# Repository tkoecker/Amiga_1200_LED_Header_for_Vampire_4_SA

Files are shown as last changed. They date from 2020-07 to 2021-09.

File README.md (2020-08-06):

# Amiga 1200 LED Header for Vampire 4 Standalone

I've printed the fantastic Vampire 4 Standalone enclosure by Jörgen Bilander (see https://github.com/jbilander/Vampire_V4_Standalone_Enclosure). It allows to mount an Amiga 1200 LED PCB, however the Vampire 4 SA does not have any header to connect this board. This is why I've made a small adapter PCB that adds an Amiga 1200 LED header to the Vampire 4 SA.

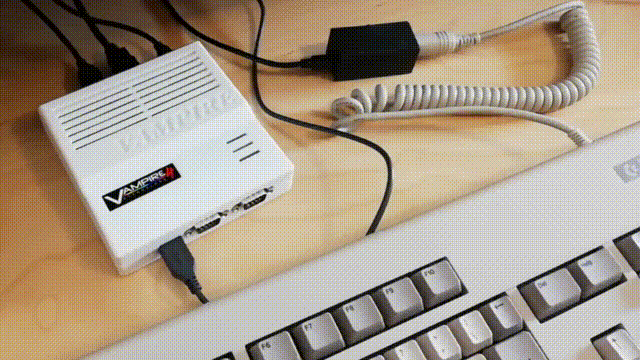
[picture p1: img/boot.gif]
Video of V4SA booting with A1200 LEDs


(LED activity in the image above: Power on, SD card access to load kick rom, Amiga OS booting, Amiga OS mounting/reading SD card)

It uses an IC that provides 4 opamps. One opamp each is used to sense the power and drive LED state, adding only a neglectable additional load to the outputs of the V4SA. The two remaining opamps are for the floppy LED which can be either be triggered from an active low or an active high signal (selectable using a solder jumper).
The chosen opamps have rail-to-rail outputs which allows to drive the LEDs on the Amiga 1200 LED PCB with a similar voltage as the original Amiga 1200 circuitry.

*WARNING:* There is some fine soldering needed to install the PCB on the V4SA. If you do not feel confident doing that, please ask somebody who does. It would be a pitty if you ruin your nice V4SA when installing this board.

Adapter (please note that the images were taken from an old board version, the current one has less solder pads - they are not needed):

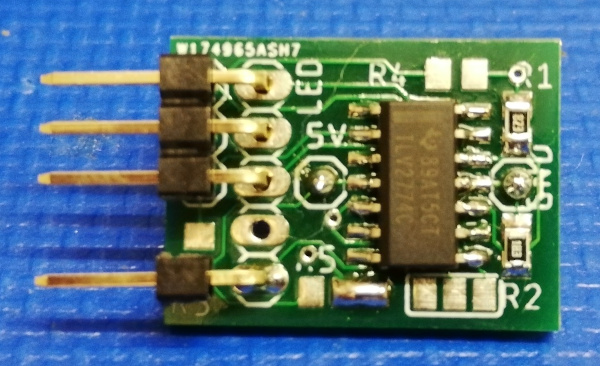
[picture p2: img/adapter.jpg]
Adapter


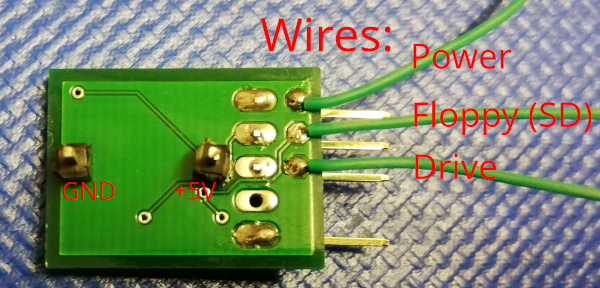
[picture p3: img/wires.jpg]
Adapter wires


The board sits on top of the 68000 pins of the Vampire 4 SA and gets +5V and GND from there.

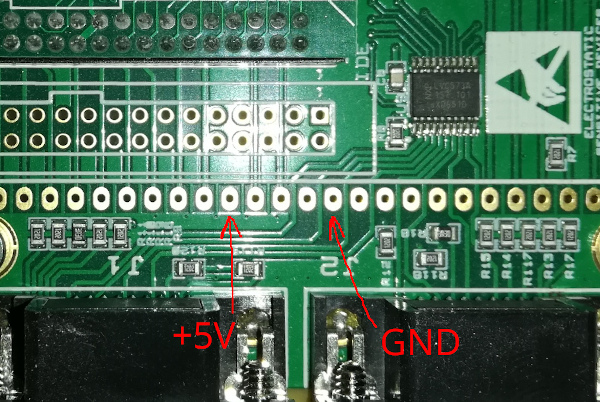
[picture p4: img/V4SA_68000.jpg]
Adapter location


It also needs two wires to the original power and drive LEDs of the V4SA to sense their state.

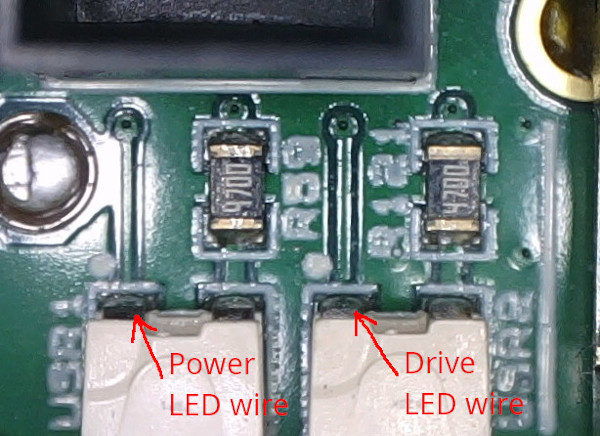
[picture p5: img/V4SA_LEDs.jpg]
Original LED wires


For using the floppy led for the micro-SD card access a wire to pin 2 of the micro-SD card slot of the V4SA is needed.

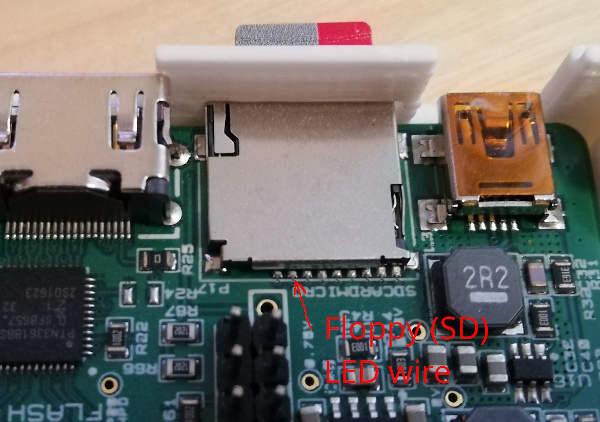
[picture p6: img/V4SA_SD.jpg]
SD wire


If you want use the floppy led you need to connect a solder jumper to select whether the signal is active-low or active-high:

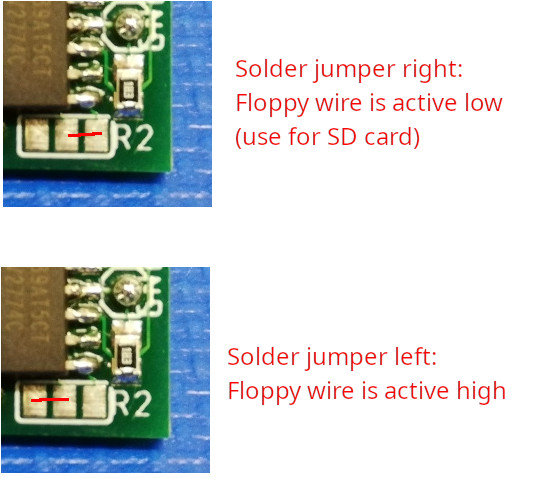
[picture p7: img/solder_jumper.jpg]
Solder jumper


[Link to PCB on PCBWay](https://www.pcbway.com/project/shareproject/Amiga_1200_LED_Header_for_Vampire_4_Standalone.html)

BOM:
- R1, R2: 82 kOhm 0805 SMD resistor
- IC1: TLV2774CD
- 5V/GND pins: 1 pin of a straight pin header each
- LED pin header: 5 pin angled pin header

Images:

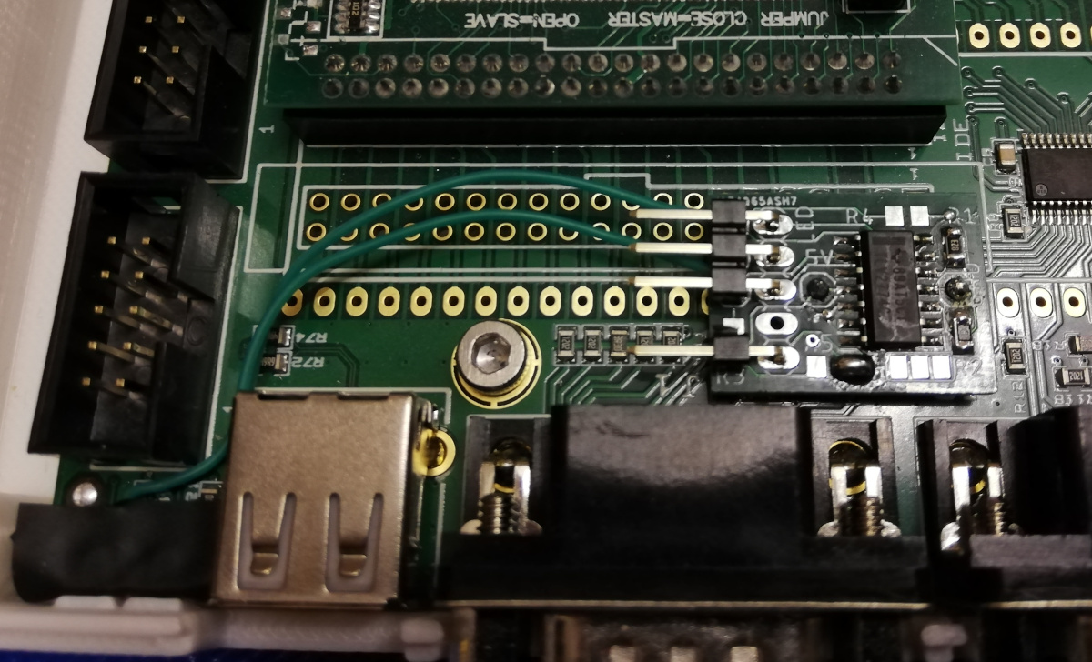
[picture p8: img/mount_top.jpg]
Mount top

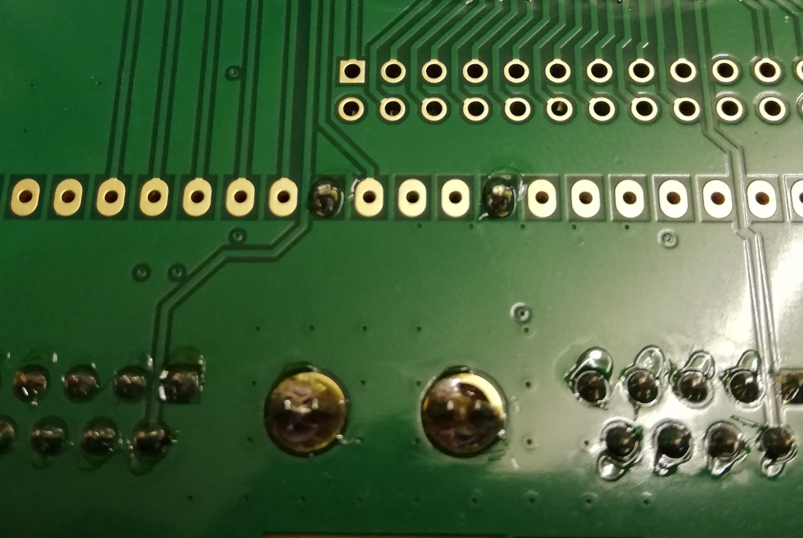
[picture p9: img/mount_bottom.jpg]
Mount bottom


***DISCLAIMER:***

This hardware/software is provided "as is", and you use the hardware/software at your own risk. Under no circumstances shall any author be liable for direct, indirect, special, incidental, or consequential damages resulting from the use, misuse, or inability to use this hardware/software, even if the authors have been advised of the possibility of such damages.

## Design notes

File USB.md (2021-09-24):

As the official USB upgrade board for the V4 does not fit with the LED board installed I did an alternative USB upgrade:

- Ordered a [dual port USB socket](https://www.conrad.at/de/p/usb-einbaubuchse-2-0-dual-port-buchse-einbau-tc-a-usb-a-2p-203-usb-a-1586531-tru-components-inhalt-1-st-1586531.html):
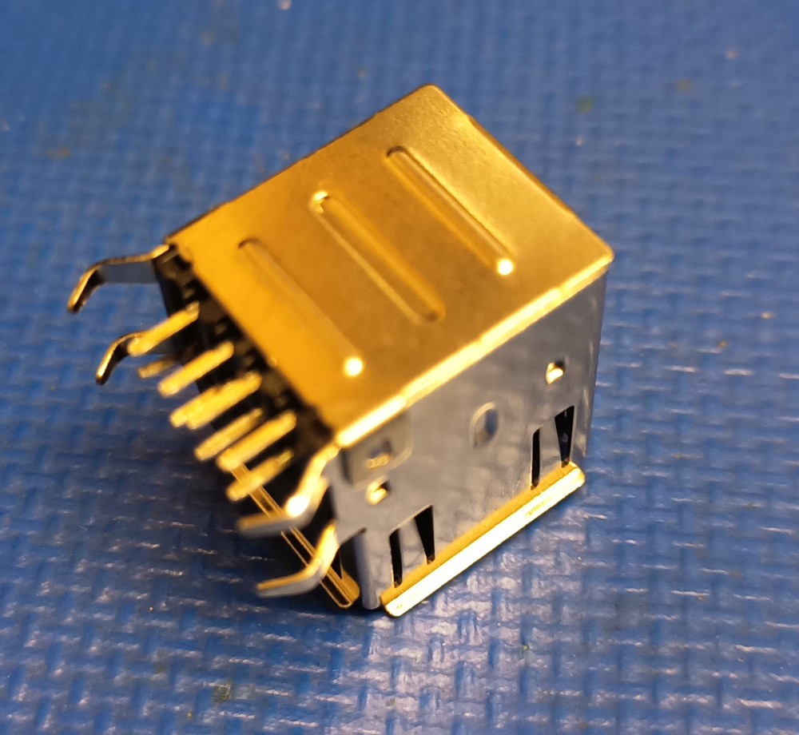
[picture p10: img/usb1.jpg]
usb1

- Removed the cover on the back:
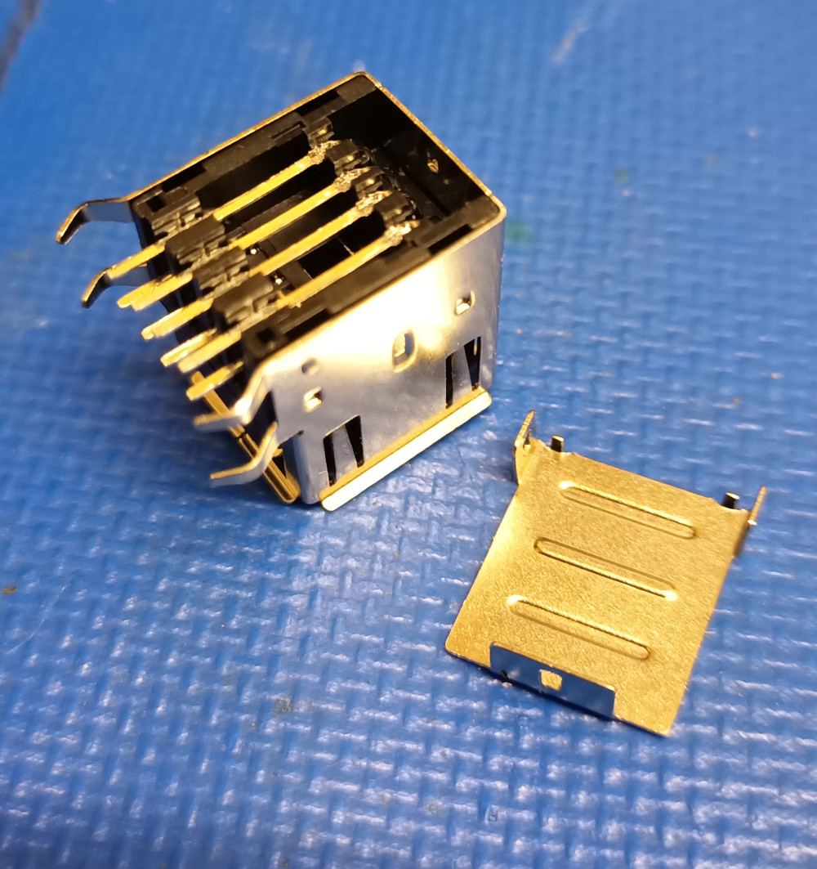
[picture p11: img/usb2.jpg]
usb2

- Bent up the pins of the upper USB port and connected the +5V and GND pins of the first socket to those of the 2nd socket.
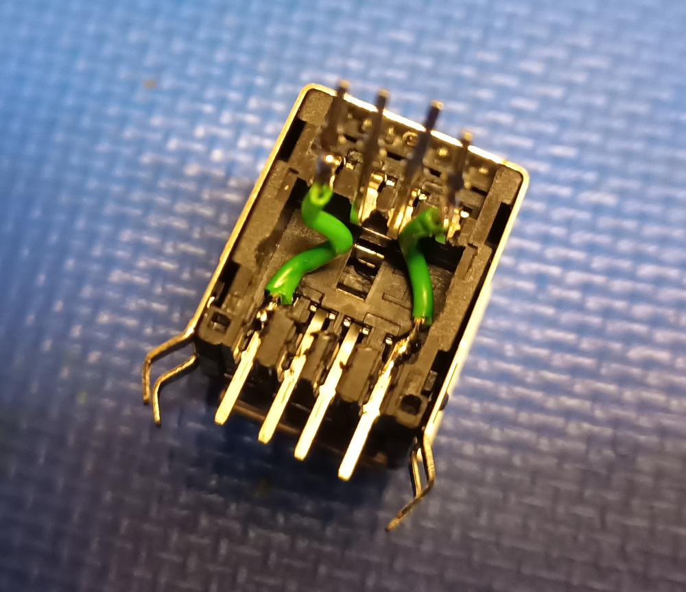
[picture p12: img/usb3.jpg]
usb3

- Bent the pins of the upper USB socket back, and gave them a right angle at the end so that they exit on the back.
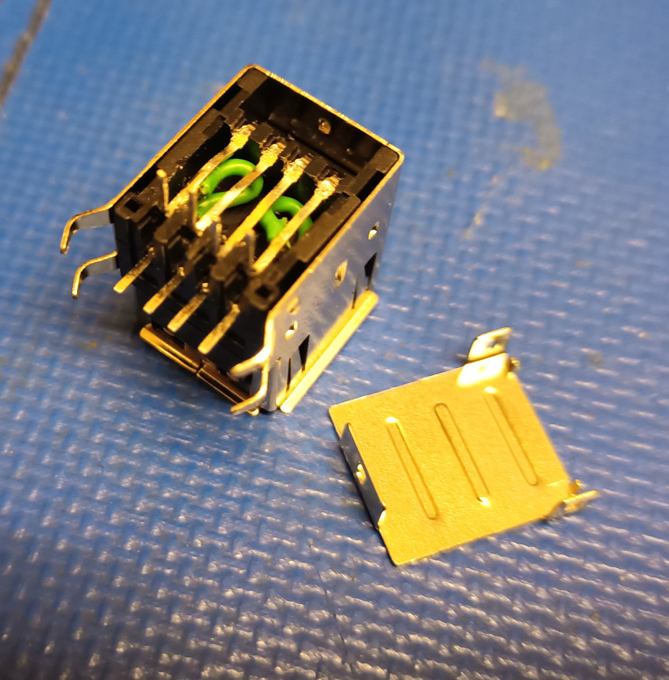
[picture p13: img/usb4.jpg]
usb4

- Put some insulation tape on the pins. Cut out an opening on the back cover so that the pins can be routed out on the back. Put on the back cover again, and cut off the two mounting pins at the back. Ensure that there es enough clearance to the resistor R72 on the V4 board!
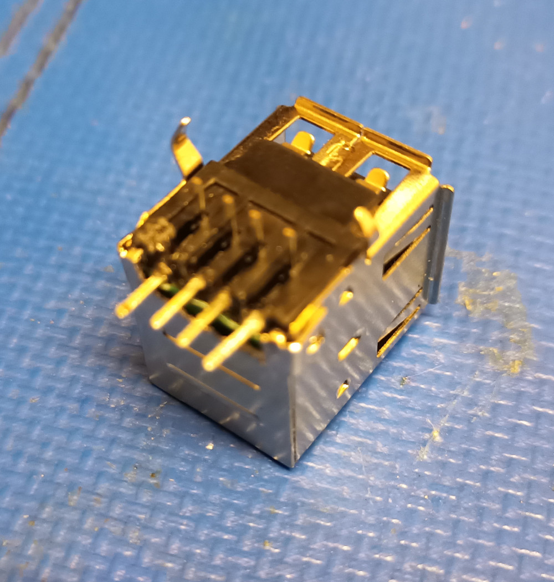
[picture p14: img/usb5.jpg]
usb5

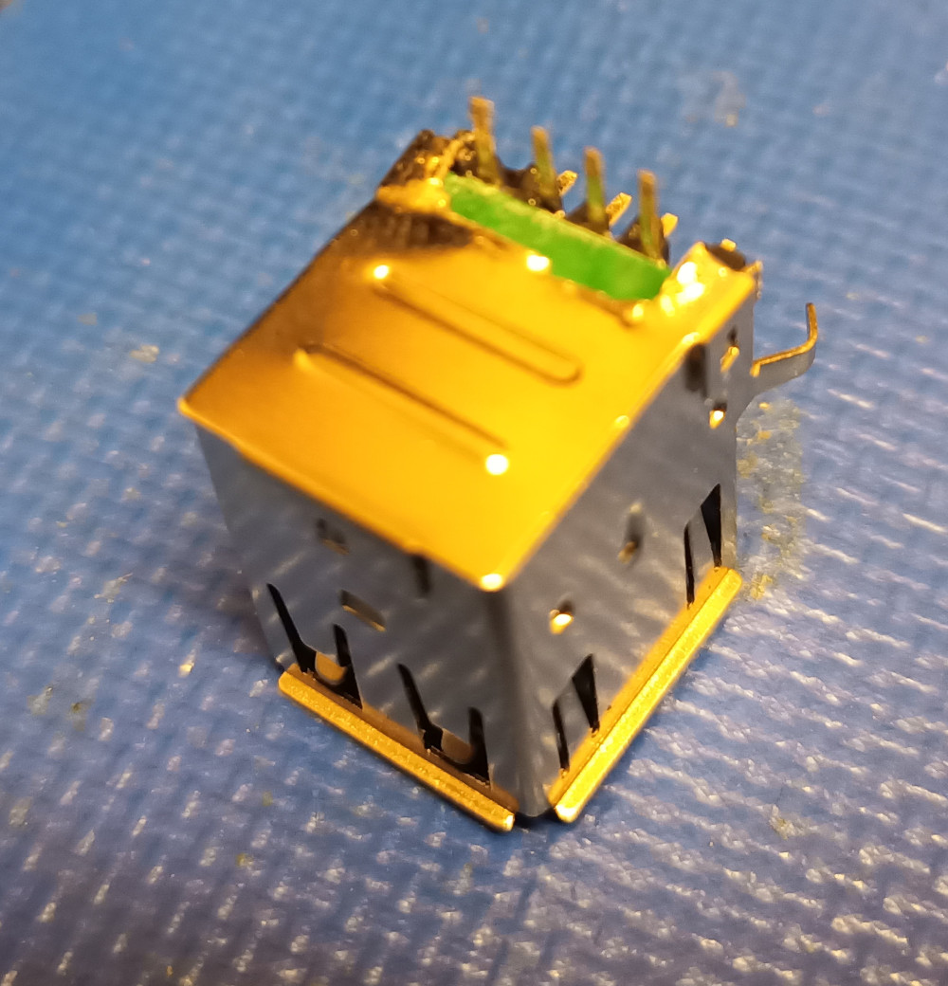
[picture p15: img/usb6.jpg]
usb6

- Put the resistors (0805), and two cut jumper wires on a perfboard. View from the back:
```
        V4
Pin 2         Pin 1
 |              |
 o----.    .----o
 |    |    |    |
.-.  .-.  .-.  .-.
|R|  |R|  |R|  |R|
|1|  |2|  |3|  |4|
'-'  '-'  '-'  '-'
 |    |    |    | 
 o--------------'
 |    |    |
 |    |    |
GND   D+   D-   +5V
        USB

R2, R3: 47 Ohm
R1, R4: 15 kOhm
        
```
Put some insulation tape on the back of the perfboard and connected it to the pins of the 2nd USB socket.
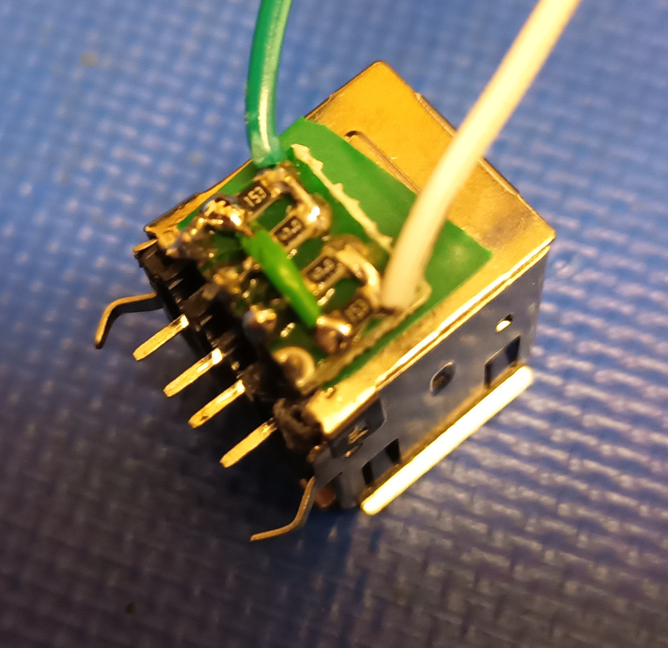
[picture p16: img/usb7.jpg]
usb7

- Desoldered the original single USB socket of the V4, soldered in the new dual port USB socket and connected the jumper wires.
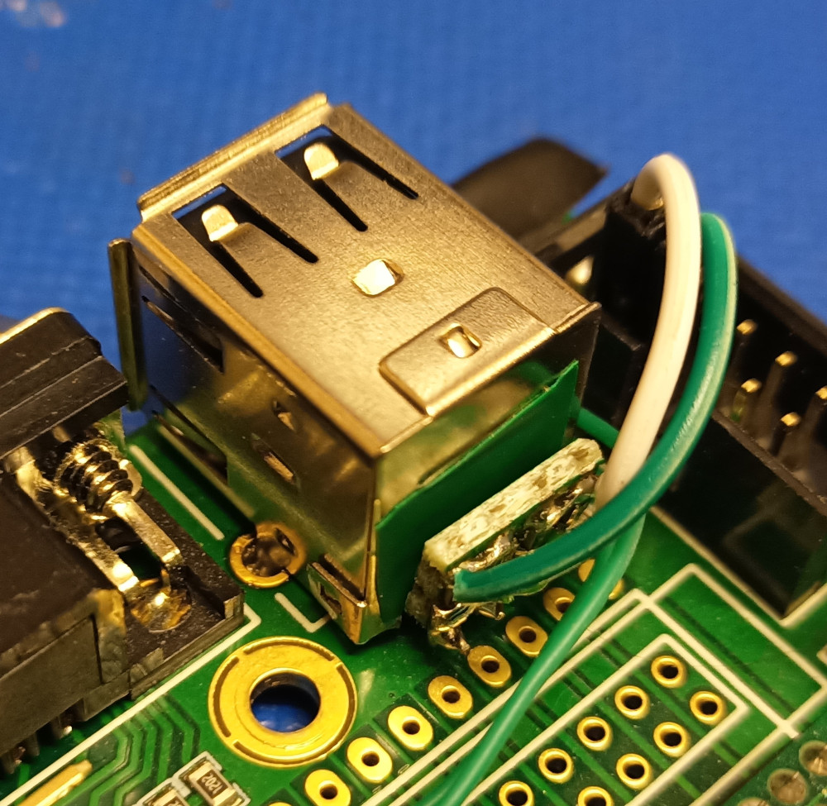
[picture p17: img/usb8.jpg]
usb8

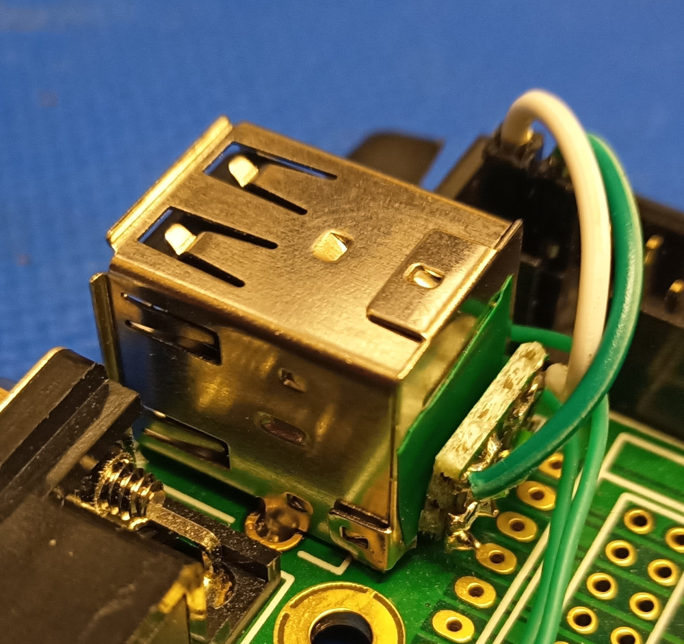
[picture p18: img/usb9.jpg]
usb9


***DISCLAIMER:***

This hardware/software is provided "as is", and you use the hardware/software at your own risk. Under no circumstances shall any author be liable for direct, indirect, special, incidental, or consequential damages resulting from the use, misuse, or inability to use this hardware/software, even if the authors have been advised of the possibility of such damages.

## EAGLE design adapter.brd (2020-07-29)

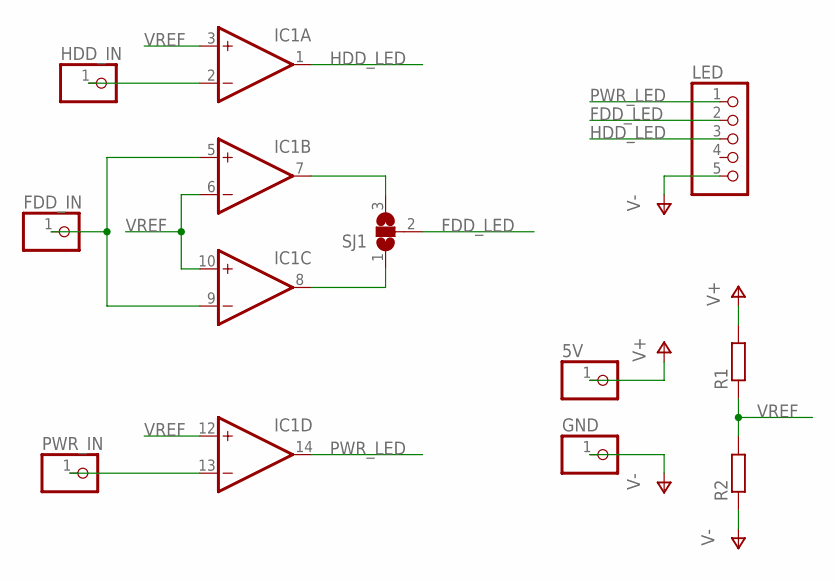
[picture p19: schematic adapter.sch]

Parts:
5V: PINHD-1X1; 1X01
FDD_IN: PINHD-1X1; 1X01
GND: PINHD-1X1; 1X01
HDD_IN: PINHD-1X1; 1X01
IC1: OP11D; SO14
LED: PINHD-1X5; 1X05
PWR_IN: PINHD-1X1; 1X01
R1, R2: R-EU_R0805; R0805
SJ1: SJ2W; SJ_2

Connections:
FDD_IN: FDD_IN.1, IC1.5 (+IN), IC1.9 (-IN)
FDD_LED: LED.2, SJ1.2
HDD_IN: HDD_IN.1, IC1.2 (-IN)
HDD_LED: IC1.1 (OUT), LED.3
unnamed: IC1.7 (OUT), SJ1.3
unnamed: IC1.8 (OUT), SJ1.1
PWR_IN: IC1.13 (-IN), PWR_IN.1
PWR_LED: IC1.14 (OUT), LED.1
V+: 5V.1, IC1.4 (V+), R1.2
V-: GND.1, IC1.11 (V-), LED.5, R2.1
VREF: IC1.3 (+IN), IC1.6 (-IN), IC1.10 (+IN), IC1.12 (+IN), R1.1, R2.2

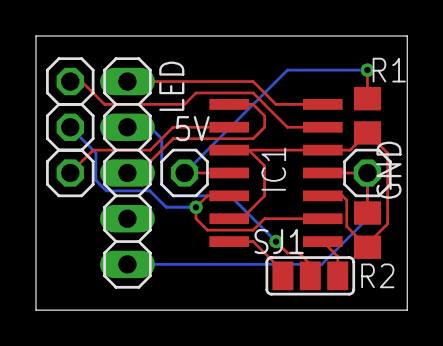
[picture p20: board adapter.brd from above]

Board: 2 copper layers, 20.6 x 15.2 mm, 10 parts (0 on the bottom side), 11 nets.
